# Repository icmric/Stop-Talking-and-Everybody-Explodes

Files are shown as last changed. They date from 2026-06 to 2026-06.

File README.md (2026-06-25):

# Stop Talking and Everybody Explodes
Stop talking and everybody explodes is an open-source take on the popular computer game [Keep Talking and Everybody Explodes](https://keeptalkinggame.com/), transforming it into a physical game to play with your friends!

You must work closley with the other player to solve a series of puzles and work around events all before the time runs out, resulting in a regrettable increase in room temperature!

This game is best enjoyed by using a physical copy of the manual (download and print manual.pdf), however an online mobile-friendly version is also avalible at [manual.ericmcc.com](https://manual.ericmcc.com/) (or the raw pdf at [staee.ericmcc.com](https://staee.ericmcc.com/))

This game was put together by a team of 6 of us for a university project, while there may be some future updates made we do not gaurantee any further maintinance

## Build Process
All components used are very generic and inexpencive. I have linked each item below to where i purchased it on aliexpress, however I recomend looking for potentially better prices as they change often! 

### Hardware
* [Arduino Mega 2560](https://www.aliexpress.com/item/32837393855.html)
* [LED Bar](https://www.aliexpress.com/item/1005007198230035.html) (Note: You must solder a 220Ω or 330Ω resistor on EVERY positive terminal for it to function. Pre wired ones basically dont exist, [there are some](https://www.aliexpress.com/item/1005007804923693.html) however they require seperate packages and work a bit differently)
* [TM1637 4 bit display](https://www.aliexpress.com/item/1005009269502486.html)
* 2x [Rotary Encoders](https://www.aliexpress.com/item/1005009578504178.html)
* [Microphone switch](https://www.aliexpress.com/item/1005009742731611.html)
* [Small buzzer](https://www.aliexpress.com/item/1005007287329656.html)
* [WS2182B-64 8x8 RGB LED Matrix](https://www.aliexpress.com/item/1005010747838637.html)
* [I<sup>2</sup>C LCD Display](https://www.aliexpress.com/item/1005011648206201.html)
* The + and - rail from a [400 pin bread board](https://www.aliexpress.com/item/1005006713173854.html)
* [12mm Key Switch](https://www.aliexpress.com/item/1005009886103118.html)
* 2x [12mm Momentary Push Switch](https://www.aliexpress.com/item/32814739163.html) (Note: A pre wired one may be wise as the raw connectors are very difficult to solder)
* A bunch of 10mm and 20mm [DuPont Cables](https://www.aliexpress.com/item/4000204858217.html)
* A small power bank, any should work but i use [this one](https://www.aliexpress.com/item/1005008094289372.html)

Not directly avalible for purchase is the enclosure which is custom made. All required files have been included so you can print your own!
  
  **Note:** For standard 3d prints use the .STL files, if you would like to print the text in a different colour use the .3mf file. There is also the .f3d if you would like to tweak the design!
  
  **Note:** Make sure you print **10** of the DuPont holders, my recomendation is to print using 5 colours (printing 2 in each colour) however you *could* get away without this

### Software
* Install the [Arduino IDE](https://docs.arduino.cc/software/ide/), download the code in the repository, unzip it and open it using the IDE
* There are a few external packages you must install in the IDE to get everything working, these are all listed at the top of the .ino file!
* After everything is installed connect up the arduino to your computer and upload the code

### Setup
Now that the ardino has the software uploaded to it, disconnect it from the computer before plugging in all the hardware

The .ino file contains a pin map at the top detailing which pin must be connceted to which component. Make sure you also connect up all the VCC and GND pins to the breadboard, connecting each rail to the arduino!

I would also sugest putting a bit of hot glue on the connectors as the DuPont cables can sometimes slide off the components, however you can probably get away without glue.

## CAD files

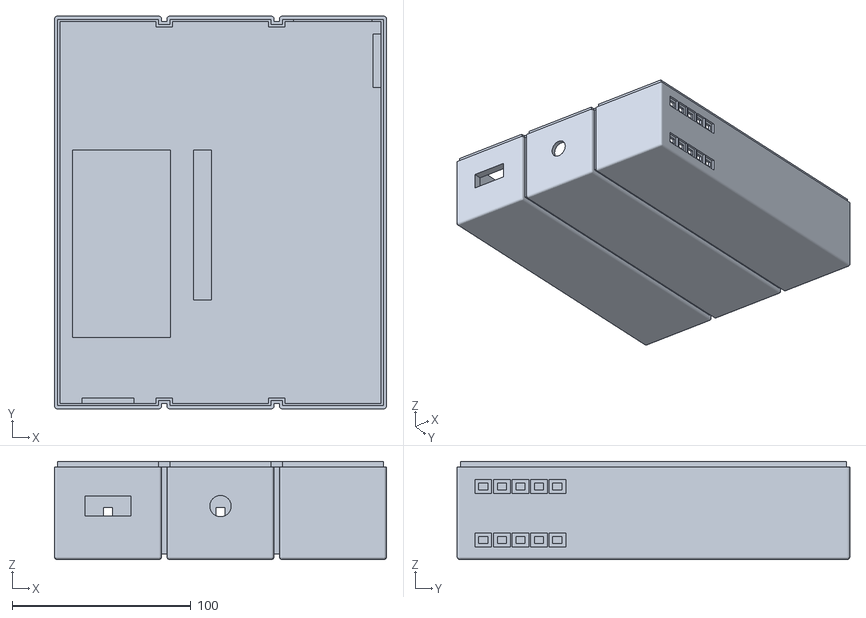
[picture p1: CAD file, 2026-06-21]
3D Models/Body.stl
186.0 x 220.0 x 55.0

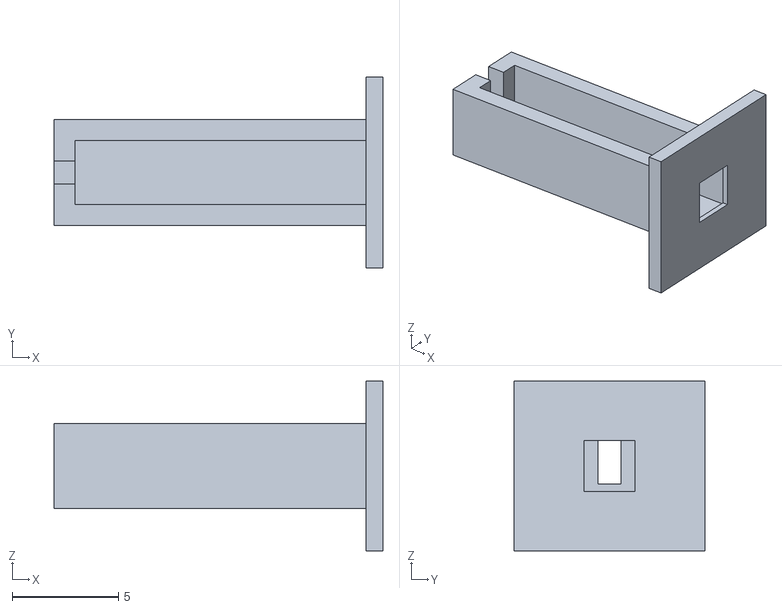
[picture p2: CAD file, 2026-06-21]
3D Models/DuPont Adaptor.stl
15.5 x 9.00 x 8.00

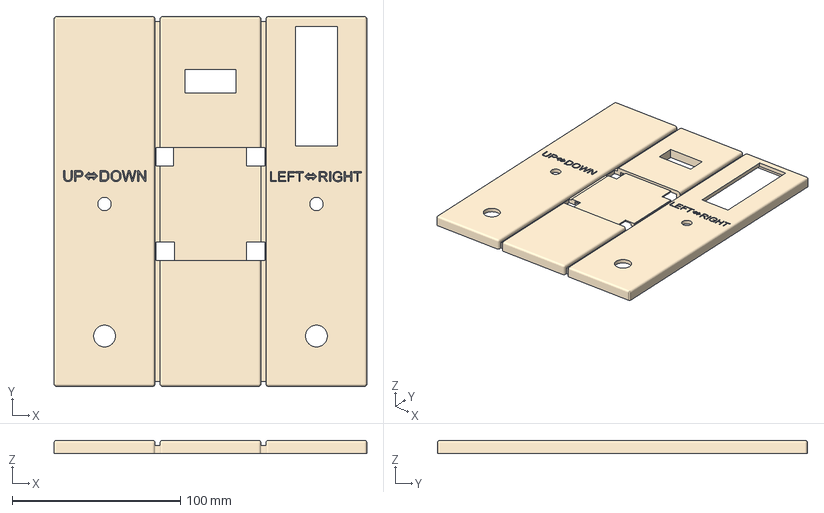
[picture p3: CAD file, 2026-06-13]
3D Models/Lid.3mf
186.0 x 220.0 x 8.00 mm
ARR
G
H
I
Lid
R
T
arr
d
e
f
l
n
o
p
t
u
w

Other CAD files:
3D Models/Lid.stl
3D Models/Stop talking and Everybody Explodes.f3d

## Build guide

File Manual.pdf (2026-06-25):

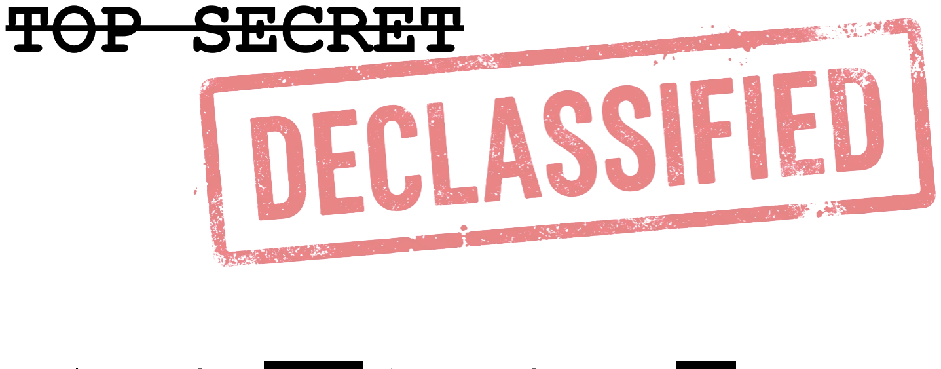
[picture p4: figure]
TOP SECRET

Authority: Executive Order | 13526 | | Record Group | 218

# OPERATIONAL FIELD MANUAL: EX-99

## EXPLOSIVE DEVICE NEUTRALISATION & DISPOSAL PROCEDURES

FILE NO: | 88-B-ALPHA-9
PREPARED BY: | DEFENSE SPECIAL WEAPONS AGENCY

DATE OF DECLASSIFICATION: MAY 13, 2026 Reason: Request under Freedom of Information Act 1982

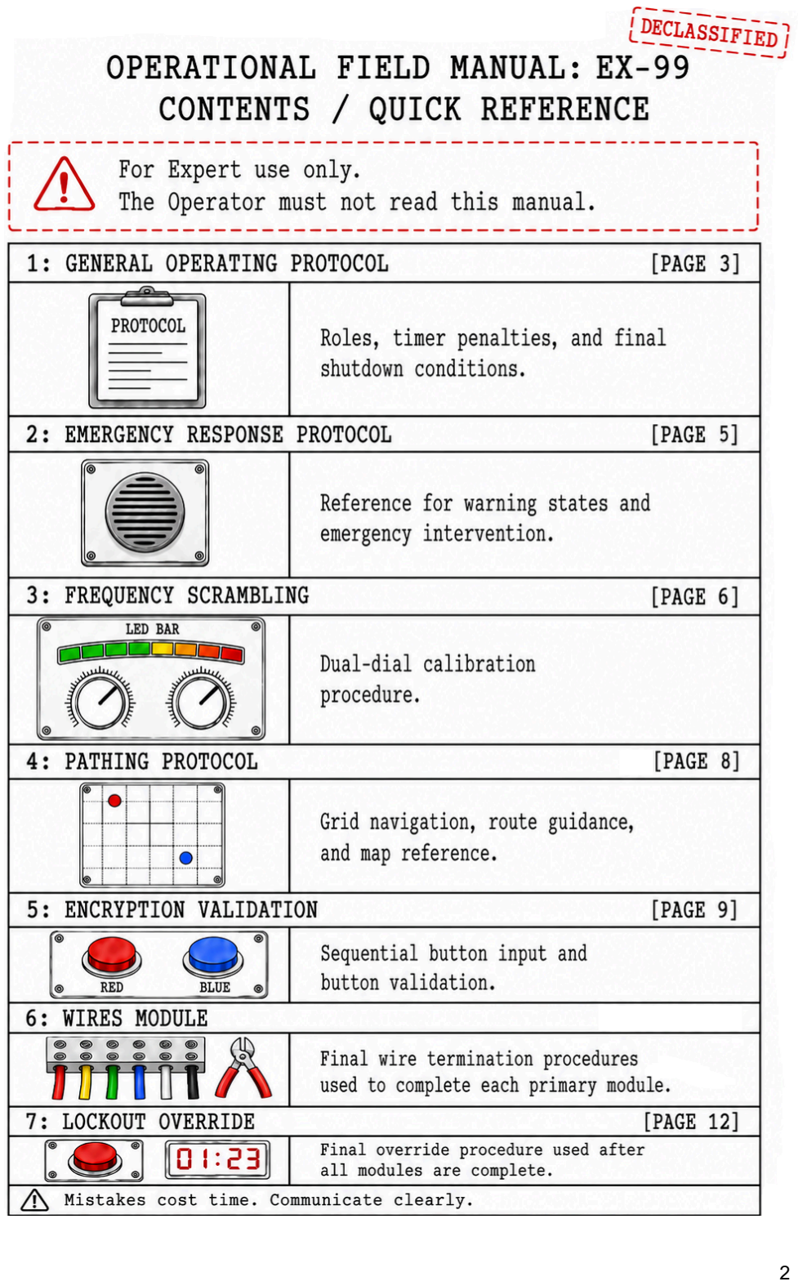
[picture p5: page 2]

## SECTION 0 一 GENERAL OPERATING PROTOCOL

DOCUMENT CLASSIFICATION: RESTRICTED ACCESS
SUBJECT: EXPLOSIVE DEVICE DEFUSAL PROCEDURE

MISSION OBJECTIVE: PROJECT FIRECRACKER (CONFIDENTIAL)
Your primary directive is to guide your field asset through the non-destructive neutralisation of an active, multi-module explosive device before the clock runs out. Failure to follow these exact procedures will result in a rapid increase in room temperature.

### 0.1 The Golden Rules

Corporate liability insurance strictly covers your designated role and your role only:
- The Expert (You): The brains, you must maintain zero physical and visual contact with the bomb. Far too risky up close anyway.
- The Operator: They are the hands, they are paid to turn dials and pull wires. Reading this manual is well above their pay grade.

### 0.2 Shift Schedule

To ensure compliance with labour laws, please closely follow this procedure:
- Managing Time: Keep watching the timer. This lets you know how long you have until you lose. It cannot be paused or reset, and will not wait for you to refill your coffee.
- Efficiency Tax: Being bad at your jobs is ill-advised. Any mistake made by the operator tends to cause instability in the device, resulting in the loss of at least 3 seconds.
- Clock in: When you’re ready to begin, get the operator to pick up the key, insert it and turn the device on. Congratulations, you are now in danger
- Clocking out: Once and only once every single section is fully neutralised, the operator must turn the key to the OFF position. Turning it off before properly neutralising the device is ill advised due to the sheer amount of paperwork and clean-up involved.

# Module Defusal Procedures

## EXPERT EYES ONLY

===================================

## ⚠ EMERGENCY RESPONSE PROTOCOL ⚠

===================================

### THERMAL INSTABILITY DETECTED

The amateur who wired up the device clearly didn't understand much about power regulation. Whenever a module is taken offline there is a sudden and violent voltage spike which has a chance to send the bomb into thermal runaway, which even for a bomb is pretty unsafe.

Luckily due to their poor design knowledge the workaround is incredibly simple, and from our understanding should hopefully also prevent it from overheating in the future. The only slight downside is that it requires the operator sticking their face within a few centimetres of the device while it's unstable!

Whenever a module is taken offline there is a chance to send the bomb into thermal runaway!

This will be made evident by the following indicators:
- Some displays beginning to flicker
- The screen displays “Core Overheating”
- A really annoying alarm sound

When the operator experiences any of these things, IMMEDIATELY return to this page. Tell the operator to stop what they are doing and perform the following steps:
- Look for a circular black vent on the back right of the device.
- Blow into the vent to cool it down.
- Maintain a constant stream of cool air until the beeping stops, this should only take about 5-10 seconds.

## SECTION 1 一 FREQUENCY SCRAMBLING MODULE

DOCUMENT CLASSIFICATION: RESTRICTED ACCESS
MODULE DESIGNATION: DUAL-DIAL CALIBRATION SYSTEM MODULE ID: 54F-3W1-R35

### 1.1 Dial Calibration Protocol

This module requires the Operator to turn the two dials in a specific sequence to scramble the communication systems within the bomb. Extensive research shows that there are 5 possible combinations the device could want, all helpfully tied to the serial number. Figuring out which combination to use takes only a little bit of primary school maths.

Incorrect inputs will incur a 3 second penalty.

- Sum the 4 digits of the serial number (ABCD-XXXX).
- Calculate the sum of these digits, modulo 5 (keep subtracting 5 until you can’t, it's the number left over).
- Look that number up in the table below and instruct the operator to turn the corresponding dials until they click the respective number of times.

They’ll know they’ve done this step correctly if the LED bar on the front of the device decreases after each set of dial turns.
0 | 1 | 2 | 3 | 4
3 DOWN | 2 RIGHT | 4 DOWN | 3 RIGHT | 1 UP
2 LEFT | 3 UP | 1 LEFT | 2 UP | 4 RIGHT
2 UP | 1 RIGHT | … | 1 LEFT | 1 DOWN
… | … | … | 2 DOWN | …

### 1.2 Terminal Node De-Energisation

After successfully scrambling the frequencies, you need to have the Operator permanently disable the communication module, by cutting or ripping out the wires on the side of the device.

The behaviour of the device if the Operator cuts the wrong wire is technically "unknown". Common speculation around the office is that it will trigger an immediate detonation, drastically shorten the countdown timer, or do absolutely nothing at all. Given the total lack of consensus, we strongly recommend you actually pay attention to the next step so the Operator doesn't fumble the only direct instruction you're about to give them.

Be Careful, if the Operator cuts the wrong wire it will trigger an immediate detonation!
- Ask the operator for the final digit in the serial number (ABCD-123X).
- Take this number to the handy table below and find the corresponding target wire.
- Tell the operator to terminate the wire. (Or just pull).
Serial Number Final Digit | Target Wire
0 or 5 | 🟥 RED (1) 🟥
1 or 6 | 🟦 BLUE (2) 🟦
2 or 7 | 🟨 YELLOW (3) 🟨
3 or 8 | 🟩 GREEN (4) 🟩
4 or 9 | ⬛ BLACK (5) ⬛
* The number denotes the wire when looking at the top row of plugs, count from left to right

## SECTION 2 一 PATHING PROTOCOL MODULE

DOCUMENT CLASSIFICATION: RESTRICTED ACCESS MODULE DESIGNATION: GRID-BASED PATHFINDING SYSTEM MODULE ID: M4Z-3W1-R35

### 2.1 Interface Asymmetry

The operator should now have a grid of dots light up on the front of the device. This is an invisible maze. The operator cannot see the walls, but luckily, you can.
Through a monumental waste of our department's afternoon we managed to reverse-engineer these layouts for this manual.

Do not allow them to turn dials randomly; we do not have the budget for another prolonged structural incident.

### 2.2 Map Identification

The hardware cycles through four separate layout configurations.
To identify which structural failure you are dealing with:
- Extract the second letter of the device serial number (AXCD-1234) from the Operator.
- Match that letter to the corresponding ranges to isolate the active map on the following page.

### 2.3 OPERATION PROTOCOL

Once the structural layout is identified, clear the active grid parameters by following the strict sequence:
- Instruct the Operator to relay the location of the two active glowing dots.
- The Red Dot represents the Operator’s current position.
- The Blue Dot identifies the intended target destination.
- Relay navigation instructions to the Operator one step at a time.

Any physical collision between the Operator and a grid wall will result in an immediate 3-second time penalty.

A - G

O - U

H - N

V - Z

### 2.4 Terminal Node De-Energisation

Bypassing the software layer merely advances your shift closer to standard clock-out parameters. To permanently drop the pathing algorithms offline, you must additionally command a physical hardware termination.

While the internal analytics department remains reasonably confident in this data matrix , any unexpected post-mortem detonation must be
manually documented and reported to Sgt. | redacted | for internal
investigation.

Be Careful, if the Operator cuts the wrong wire it will trigger an immediate detonation!

1. Request the first digit of the serial number (ABCD-X234) from the operator.
2. Match that digit to the matrix below to isolate the designated wire.
3. Tell the operator to terminate the wire. (Or just pull).
Serial Number First Digit | Target Wire
0 or 1 | 🟦 BLUE (2) 🟦
2 or 3 | 🟨 YELLOW (3) 🟨
4 or 5 | 🟩 GREEN (4) 🟩
6 or 7 | ⬛ BLACK (5) ⬛
8 or 9 | 🟥 RED (1) 🟥

## SECTION 3 一 ENCRYPTION VALIDATION MODULE

DOCUMENT CLASSIFICATION: RESTRICTED ACCESS
MODULE DESIGNATION: SEQUENTIAL INPUT VALIDATION SYSTEM MODULE ID: 3V3-N0D-DW1

### 3.1 Description

The architect of this device implemented a sequential validation system to weed out operators with sub-standard short-term memory. The module consists of a red and a blue button.

Instruct the Operator to, in quick succession, input the button sequence derived from the serial number digits read left to right:
- Even numbers: Direct operator to press the RED Button
- Odd numbers: Direct operator to press the BLUE Button

### 3.2 Terminal Node De-Energisation

Disconnecting this hardware layer is an administrative nightmare because our software division is entirely incompetent, leaving this routing matrix unnecessarily convoluted

- Request the last letter of the serial number (ABCX-1234) from the Operator.
- Isolate the designated wire via the chart below.
- Instruct the Operator to terminate the wire. If a sudden detonation occurs, file a formal grievance report regarding the intern's logic.
Serial Number Last Letter | Target Wire
A, F, K, P, U, OR Z | 🟨 YELLOW (3) 🟨
B, G, L, Q, V, OR W | 🟩 GREEN (4) 🟩
C, H, M, R, X, OR Y | ⬛ BLACK (5) ⬛
D, I, N, S, OR T | 🟥 RED (1) 🟥
E, J, OR O | 🟦 BLUE (2) 🟦

## SECTION 4 一 LOCKOUT OVERRIDE MODULE

DOCUMENT CLASSIFICATION: RESTRICTED ACCESS MODULE DESIGNATION: REACTION TRIGGER EMERGENCY MODULE ID: B16-R3D-BU7

### 4.1 OPERATION PROTOCOL

The amateur threat lazily mapped this final lockout override routine directly to the same red button utilised during your encryption sequence. Once all other threats are entirely offline, the Operator may resolve this final corporate hurdle by observing the following protocol:

- Instruct the Operator to closely watch the timer count down and preferably remain calm.
- Direct the Operator to press the red button when the number in the third digit of the serial number (ABCD-12X4), appears in any position on the timer.

Commanding this input incorrectly may result in the permanent, post-mortem conclusion of your corporate employment. Once this final validation layer is cleared, refer back to your initial Shift Schedule to determine the proper administrative procedure required to officially wrap up your shift.

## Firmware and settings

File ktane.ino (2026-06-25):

/*
  ktane.ino — KTANE Bomb Defusal Game
  Arduino Mega 2560

  Players solve multiple hardware puzzle modules under a countdown timer.
  A "Defuser" operates the hardware; a "Manual Operator" reads the solution
  guide derived from the randomly-generated serial number displayed on the LCD.

  MODULES:
    Frequency Scrambler  — rotary encoder sequence
    Maze Navigator       — LED matrix pathfinding (shares encoders with Frequency)
    Core Overheating     — blow-to-cool microphone event (random trigger)
    Button Combo         — timed button sequence

  PIN MAP:
    D2, D3   Left encoder  (CLK / DT)
    D4, D5   Right encoder (CLK / DT)
    D6       Buzzer
    D7       Microphone sensor (Core module)
    D8, D9   4-digit TM1637 display (DIO / CLK)
    D10      Red button   (INPUT_PULLUP)
    D11      Blue button (INPUT_PULLUP)
    D12      Vibration motor (via transistor; active HIGH)
    D20, D21 I2C bus — LCD 16×2 (0x27)
    D22      8×8 WS2812B matrix (NeoPixel data)
    D31      Key switch
    D35,37,39,41,43,45,47,49,51,53  LED bar (10 LEDs)
    
    HARDWARE WIRE CUTTING INTERFACE (Ground-to-Pin Arrays):
    A7       Color 0: RED
    A6       Color 1: BLUE
    A5       Color 2: YELLOW
    A4       Color 3: GREEN
    A3       Color 4: BLACK
*/

#include <Wire.h>
#include <Encoder.h>
#include <LiquidCrystal_I2C.h>
#include <Adafruit_NeoPixel.h>
#include <DIYables_4Digit7Segment_TM1637.h>

#include "SerialNumber.h"

// ── Module enable enum — defined before module headers ─────────────────────

enum ActiveEncoderModule { FREQUENCY_MODULE, MAZE_MODULE };

enum GameState {
  STATE_IDLE,      // Waiting for key turn
  STATE_RUNNING,   // Game in progress
  STATE_WON,       // All modules solved; waiting for key-off to confirm disarm
  STATE_FAILED,    // Timer expired or key turned off early
  STATE_DISARMED   // Successfully disarmed
};

// ── Module headers (after enum definitions) ────────────────────────────────

#include "FrequencyModule.h"
#include "CoreModule.h"
#include "MazeModule.h"
#include "ButtonComboModule.h"
#include "LockoutModule.h"

// ── Debug / bypass flags ───────────────────────────────────────────────────
// Set to true to skip a module during development/testing.

const bool BYPASS_FREQUENCY_MODULE = false;
const bool BYPASS_MAZE_MODULE = false;
const bool BYPASS_CORE_MODULE = false;
const bool BYPASS_BUTTON_COMBO = false;
const bool BYPASS_LOCKOUT_MODULE = false;

// When true, skips the key-switch requirement and starts immediately on boot.
const bool AUTO_START_GAME = false;

// ── Pin definitions ────────────────────────────────────────────────────────

const int BUZZER_PIN = 6;
const int VIBRATION_PIN = 12;
const int KEY_SWITCH_PIN = 31;

const int ENC_LEFT_A = 2, ENC_LEFT_B = 3;
const int ENC_RIGHT_A = 4, ENC_RIGHT_B = 5;

const int DISP_DIO = 8, DISP_CLK = 9;
const int NEOPIXEL_PIN = 22;
const int NUM_PIXELS = 64;

const int LED_BAR_PINS[10] = {53, 51, 49, 47, 45, 43, 41, 39, 37, 35};

// ── Hardware objects ───────────────────────────────────────────────────────

Encoder encLeft (ENC_LEFT_A,  ENC_LEFT_B);
Encoder encRight(ENC_RIGHT_A, ENC_RIGHT_B);
LiquidCrystal_I2C lcd(0x27, 16, 2);
DIYables_4Digit7Segment_TM1637 tm1637(DISP_CLK, DISP_DIO);
Adafruit_NeoPixel matrix(NUM_PIXELS, NEOPIXEL_PIN, NEO_GRB + NEO_KHZ800);

// ── Game state ─────────────────────────────────────────────────────────────

ActiveEncoderModule activeEncoderModule = FREQUENCY_MODULE;
GameState currentGameState = STATE_IDLE;
String bombSerialNumber = "";

// ── Timer ──────────────────────────────────────────────────────────────────

const int TIMER_START_MINUTES  = 6;
const unsigned long TIMER_TOTAL_DURATION = (unsigned long)TIMER_START_MINUTES * 60UL * 1000UL;

int remainingSeconds = TIMER_START_MINUTES * 60;
bool timerRunning = false;
bool timerFinished = false;
unsigned long timerLastTick = 0;

// currentDigits mirrors the live display (MM:SS as four single digits)
int currentDigits[4] = {0, 5, 0, 0};

// ── Display state ──────────────────────────────────────────────────────────

bool serialNumberDisplayed = false;
int  lastDisplayedGameState = -1;

// ── Buzzer / vibration ─────────────────────────────────────────────────────

unsigned long buzzerLastBeepTime = 0;
unsigned long vibrationEndTime = 0;
bool vibrationContinuous = false;

const unsigned long BUZZER_INTERVAL_START = 5000;
const unsigned long BUZZER_INTERVAL_END = 90;
const unsigned long BUZZER_BEEP_DURATION = 80;
const int BUZZER_FREQ_START = 800;
const int BUZZER_FREQ_END = 2000;
const float BUZZER_INTERVAL_CURVE = 3.5f;
const float BUZZER_PITCH_CURVE = 2.8f;

void startVibration(unsigned long durationMs = 0);
void stopVibration();
void updateVibration();
void buzzerTone(int frequency, unsigned long duration);
void buzzerToneWait(int frequency, unsigned long duration, unsigned long waitMs);
void stopBuzzer();

// ── Key switch debounce ────────────────────────────────────────────────────

bool keyCurrentState = false;
bool keyLastState = false;
unsigned long keyLastChangeTime = 0;
const unsigned long KEY_DEBOUNCE_DELAY = 50;

// ── Wire-Cutting Tracking Hardware Variables ───────────────────────────────

bool frequencyWirePulled = false;
bool mazeWirePulled = false;
bool buttonComboWirePulled = false;

bool lastFrequencyWirePulled = false;
bool lastMazeWirePulled = false;
bool lastButtonComboWirePulled = false;

// ── End-sequence guard ─────────────────────────────────────────────────────

bool endSequencePlayed = false;

// =============================================================================
// LED BAR
// =============================================================================

void initializeLedBar() {
  for (int i = 0; i < 10; i++) {
    pinMode(LED_BAR_PINS[i], OUTPUT);
    digitalWrite(LED_BAR_PINS[i], LOW);

  }
}

void setLedLevel(int level) {
  level = constrain(level, 0, 10);
  for (int i = 0; i < 10; i++)
    digitalWrite(LED_BAR_PINS[i], i < level ? HIGH : LOW);
}

// =============================================================================
// MODULE QUERIES
// =============================================================================

bool allModulesSolved() {
  if (!BYPASS_FREQUENCY_MODULE && !(frequencyModuleSolved && frequencyWirePulled)) return false;
  if (!BYPASS_MAZE_MODULE && !(mazeSolved && mazeWirePulled)) return false;
  if (!BYPASS_CORE_MODULE && !coreSolved) return false;
  if (!BYPASS_BUTTON_COMBO && !(buttonComboSolved && buttonComboWirePulled)) return false;
  if (!BYPASS_LOCKOUT_MODULE && !lockoutOverrideSolved) return false;
  return true;
}

int getTotalModuleCount() {
  int n = 0;
  if (!BYPASS_FREQUENCY_MODULE) n++;
  if (!BYPASS_MAZE_MODULE) n++;
  if (!BYPASS_CORE_MODULE) n++;
  if (!BYPASS_BUTTON_COMBO) n++;
  if (!BYPASS_LOCKOUT_MODULE) n++;
  return n;
}

int getSolvedModuleCount() {
  int n = 0;
  if (!BYPASS_FREQUENCY_MODULE && frequencyModuleSolved && frequencyWirePulled) n++;
  if (!BYPASS_MAZE_MODULE && mazeSolved && mazeWirePulled) n++;
  if (!BYPASS_CORE_MODULE && coreSolved) n++;
  if (!BYPASS_BUTTON_COMBO && buttonComboSolved && buttonComboWirePulled) n++;
  if (!BYPASS_LOCKOUT_MODULE && lockoutOverrideSolved) n++;
  return n;
}

// =============================================================================
// PENALTY
// =============================================================================

void applyPenalty(const char* /*reason*/) {
  buzzerTone(1000, 200);
  if (remainingSeconds > 3) {
    remainingSeconds -= 3;
  } else {
    remainingSeconds = 0;
    timerRunning = false;
    timerFinished = true;
    noTone(BUZZER_PIN);
  }
}

// =============================================================================
// AUDIO
// =============================================================================

void startVibration(unsigned long durationMs) {
  digitalWrite(VIBRATION_PIN, HIGH);
  if (durationMs == 0) {
    vibrationContinuous = true;
    vibrationEndTime = 0;
  } else {
    vibrationContinuous = false;
    vibrationEndTime = millis() + durationMs;
  }
}

void stopVibration() {
  digitalWrite(VIBRATION_PIN, LOW);
  vibrationContinuous = false;
  vibrationEndTime = 0;
}

void updateVibration() {
  if (vibrationContinuous || vibrationEndTime == 0) return;
  if (millis() >= vibrationEndTime) {
    digitalWrite(VIBRATION_PIN, LOW);
    vibrationEndTime = 0;
  }
}

void buzzerTone(int frequency, unsigned long duration) {
  tone(BUZZER_PIN, frequency, duration);
  
  if (!vibrationContinuous) startVibration(duration);
}

void buzzerToneWait(int frequency, unsigned long duration, unsigned long waitMs) {
  buzzerTone(frequency, duration);
  unsigned long end = millis() + waitMs;
  while (millis() < end) updateVibration();
  if (!vibrationContinuous) stopVibration();
}

void stopBuzzer() {
  noTone(BUZZER_PIN);
  digitalWrite(BUZZER_PIN, LOW);
  if (!vibrationContinuous) stopVibration();
}

void playSuccessTone() {
  const int notes[] = {523, 659, 784, 1047, 784, 659, 523};
  for (int i = 0; i < 7; i++) {
    buzzerToneWait(notes[i], 150, 200);
  }
  stopBuzzer();
}

// Short single confirm
void playStepConfirmTone() {
  buzzerToneWait(1400, 90, 110);
}

// Three-tone ascending confirm
void playModuleCompleteTone() {
  buzzerToneWait(900, 80, 90);
  buzzerToneWait(1200, 80, 90);
  buzzerToneWait(1600, 120, 140);
}

float getTimerProgress() {
  long msLeft = (long)remainingSeconds * 1000L - (long)(millis() - timerLastTick);
  msLeft = constrain(msLeft, 0L, (long)TIMER_TOTAL_DURATION);
  return 1.0f - ((float)msLeft / (float)TIMER_TOTAL_DURATION);
}

void updateBuzzer() {
  // Core alert overrides normal beeping
  if (coreMessageShown && !coreSolved) {
    unsigned long cycleTime = millis() % 1000;
    
    // Determine if the buzzer should be actively making sound right now
    bool shouldBeOn = (cycleTime < 200 || (cycleTime >= 250 && cycleTime < 450) || (cycleTime >= 500 && cycleTime < 700));
    
    static bool lastCoreSoundActive = false;
    
    if (shouldBeOn) {
      if (!lastCoreSoundActive) {
        buzzerTone(1500, 200); // Fires ONCE at the exact start of a beep window
        lastCoreSoundActive = true;
      }
    } else {
      if (lastCoreSoundActive) {
        stopBuzzer(); // Fires ONCE at the exact start of a silent window
        lastCoreSoundActive = false;
      }
    }
    return;
  }

  if (!timerRunning || timerFinished || remainingSeconds <= 0) {
    stopBuzzer();
    return;
  }

  unsigned long now = millis();

  if (remainingSeconds <= 15) {
    unsigned long interval  = 100;
    int panicFreq = 1000 + (15 - remainingSeconds) * 50;
    if (now - buzzerLastBeepTime >= interval) {
      buzzerTone(panicFreq, 50);
      buzzerLastBeepTime = now;
    }
  } else {
    float t = getTimerProgress();
    unsigned long interval = BUZZER_INTERVAL_START -
      (unsigned long)((BUZZER_INTERVAL_START - BUZZER_INTERVAL_END) * pow(t, BUZZER_INTERVAL_CURVE));
    int freq = BUZZER_FREQ_START +
      (int)((BUZZER_FREQ_END - BUZZER_FREQ_START) * pow(t, BUZZER_PITCH_CURVE));
    if (now - buzzerLastBeepTime >= interval) {
      buzzerTone(freq, BUZZER_BEEP_DURATION);
      buzzerLastBeepTime = now;
    }
  }
}

// =============================================================================
// TIMER DISPLAY
// =============================================================================

void updateTimerDisplay() {
  int mins = remainingSeconds / 60;
  int secs = remainingSeconds % 60;
  currentDigits[0] = mins / 10;
  currentDigits[1] = mins % 10;
  currentDigits[2] = secs / 10;
  currentDigits[3] = secs % 10;
  tm1637.printTime(mins, secs, true);
}

void updateCountdown() {
  // Keep display current regardless of state
  if (currentGameState == STATE_RUNNING ||
      currentGameState == STATE_WON     ||
      currentGameState == STATE_FAILED) {
    updateTimerDisplay();
  }

  if (!timerRunning || timerFinished) return;

  if (millis() - timerLastTick >= 1000) {
    timerLastTick += 1000;
    if (remainingSeconds > 0) remainingSeconds--;

    if (remainingSeconds <= 0) {
      remainingSeconds = 0;
      timerRunning = false;
      timerFinished = true;
      stopBuzzer();
      
      if (currentGameState == STATE_RUNNING || currentGameState == STATE_WON) {
        currentGameState = STATE_FAILED;
        
        // FIX: Trigger the custom expanding explosion sequence upon running out of time
        if (!endSequencePlayed) {
          tm1637.printTime(00, 00, true);
          playDetonatedSequence(true); // Passes timedOut = true for the correct ending text
          endSequencePlayed = true;
        }
      }
    }
  }
}

// =============================================================================
// LCD DISPLAY MANAGEMENT
// =============================================================================

void updateModuleCountDisplay() {
  String s = String(getSolvedModuleCount()) + "/" + String(getTotalModuleCount());
  lcd.setCursor(16 - s.length(), 1);
  lcd.print(s);
}

void displaySerialNumber() {
  lcd.clear();
  lcd.setCursor(0, 0);
  lcd.print("SN:"); lcd.print(bombSerialNumber);
  updateModuleCountDisplay();
}

void updateDisplayState() {
  if (currentGameState != lastDisplayedGameState) {
    if (currentGameState == STATE_IDLE) {
      lcd.clear();
      lcd.setCursor(0, 0); lcd.print("BOMB ARMED");
      lcd.setCursor(0, 1); lcd.print("TURN KEY");
    }
    lastDisplayedGameState = currentGameState;
    serialNumberDisplayed  = false;
  }

  if (!serialNumberDisplayed &&
      (currentGameState == STATE_RUNNING || currentGameState == STATE_WON)) {
    if (!coreTriggered || coreSolved) {
      displaySerialNumber();
      serialNumberDisplayed = true;
    }
  }

  if (serialNumberDisplayed && (!coreTriggered || coreSolved))
    updateModuleCountDisplay();
}

// =============================================================================
// WIN / LOSE SEQUENCES
// =============================================================================

void playDisarmedSequence() {
  lcd.clear();
  lcd.setCursor(0, 0); lcd.print("** DISARMED **");
  lcd.setCursor(0, 1);
  int m = remainingSeconds / 60, s = remainingSeconds % 60;
  lcd.print(m); lcd.print(":");
  if (s < 10) lcd.print("0");
  lcd.print(s); lcd.print(" remaining");

  // Smoothly charge up the LED bar level
  for (int i = 1; i <= 10; i++) { 
    setLedLevel(i); 
    delay(60); 
  }

  // Cinematic Green Ripple Wave expanding outward from the center
  // dx and dy calculate the distance squared from the center 4 pixels using integer math
  for (int wave = 0; wave < 5; wave++) {
    // Satisfying ascending laser arpeggio paired with each wave step
    tone(BUZZER_PIN, 400 + (wave * 250), 60);
    
    for (int y = 0; y < 8; y++) {
      for (int x = 0; x < 8; x++) {
        int dx = 2 * x - 7;
        int dy = 2 * y - 7;
        int distSq = dx * dx + dy * dy;
        int pixelIdx = y * 8 + x;

        if (wave == 0 && distSq <= 2)   matrix.setPixelColor(pixelIdx, 0x00FF00); // Ring 0 (Center)
        if (wave == 1 && distSq == 18)  matrix.setPixelColor(pixelIdx, 0x00FF00); // Ring 1
        if (wave == 2 && distSq == 50)  matrix.setPixelColor(pixelIdx, 0x00FF00); // Ring 2
        if (wave == 3 && distSq >= 98)  matrix.setPixelColor(pixelIdx, 0x00FF00); // Ring 3 (Corners)
      }
    }
    matrix.show();
    delay(100);
    
    // Dim the trailing edge of the wave for a smooth ripple effect
    for(int i = 0; i < 64; i++) {
      uint32_t c = matrix.getPixelColor(i);
      if (c == 0x00FF00) matrix.setPixelColor(i, 0x003300); 
    }
  }
  noTone(BUZZER_PIN);

  // Bring the whole matrix up to a warm, triumphant solid green pulse
  for (int pulse = 0; pulse < 3; pulse++) {
    for (int i = 0; i < 64; i++) matrix.setPixelColor(i, 0x00FF00);
    matrix.show();
    delay(250);
    for (int i = 0; i < 64; i++) matrix.setPixelColor(i, 0x003300);
    matrix.show();
    delay(200);
  }

  // Clear display down to a pristine off state
  for (int i = 0; i < 64; i++) matrix.setPixelColor(i, 0x000000);
  matrix.show();

  lcd.clear();
  lcd.setCursor(0, 0); lcd.print("BOMB DISARMED");
  updateModuleCountDisplay();
}

void playDetonatedSequence(bool timedOut) {

  startVibration(); // Initiate continuous haptic rumble framework

  // Multi-Stage Expanding Plasma Fireball Animation
  // Steps iterate outward through concentric distance thresholds
  for (int step = 0; step < 8; step++) {
    // Generate a violent, chaotic explosion crackle sound pitch down
    tone(BUZZER_PIN, random(1800 - (step * 200), 2400 - (step * 200)), 40);

    for (int y = 0; y < 8; y++) {
      for (int x = 0; x < 8; x++) {
        int dx = 2 * x - 7;
        int dy = 2 * y - 7;
        int distSq = dx * dx + dy * dy;
        int pixelIdx = y * 8 + x;

        // Map colors dynamically relative to the expanding shockwave front
        if (distSq <= 2) { // Ring 0 (Center core)
          if (step < 2) matrix.setPixelColor(pixelIdx, 0xFFFFFF);      // Blinding white flash
          else if (step < 4) matrix.setPixelColor(pixelIdx, 0xFFCC00); // Hot yellow
          else if (step < 6) matrix.setPixelColor(pixelIdx, 0xFF4500); // Fire orange
          else matrix.setPixelColor(pixelIdx, 0x440000);               // Cooling ash
        } 
        else if (distSq > 2 && distSq <= 18) { // Ring 1
          if (step == 1) matrix.setPixelColor(pixelIdx, 0xFFFFFF);
          else if (step < 4) matrix.setPixelColor(pixelIdx, 0xFFCC00);
          else if (step < 6) matrix.setPixelColor(pixelIdx, 0xFF4500);
          else matrix.setPixelColor(pixelIdx, 0x330000);
        } 
        else if (distSq > 18 && distSq <= 50) { // Ring 2
          if (step == 2) matrix.setPixelColor(pixelIdx, 0xFFFFFF);
          else if (step == 3) matrix.setPixelColor(pixelIdx, 0xFFCC00);
          else if (step < 6) matrix.setPixelColor(pixelIdx, 0xFF4500);
          else matrix.setPixelColor(pixelIdx, 0x110000);
        } 
        else { // Ring 3 (Outer edge bounds)
          if (step == 3) matrix.setPixelColor(pixelIdx, 0xFFFFFF);
          else if (step == 4) matrix.setPixelColor(pixelIdx, 0xFFCC00);
          else if (step == 5) matrix.setPixelColor(pixelIdx, 0xFF4500);
          else if (step == 6) matrix.setPixelColor(pixelIdx, 0xFF0000);
          else matrix.setPixelColor(pixelIdx, 0x000000);
        }
      }
    }
    matrix.show();
    delay(60);
  }
  noTone(BUZZER_PIN);

  // Dissipation phase: Fiery residual sparks twinkling and cooling down to empty
  for (int fade = 0; fade < 12; fade++) {
    for (int i = 0; i < 64; i++) {
      uint32_t c = matrix.getPixelColor(i);
      if (c > 0 && random(100) < 35) {
        matrix.setPixelColor(i, 0x000000); // Pixel burns completely out
      } else if (c == 0xFF4500 || c == 0xFFCC00) {
        matrix.setPixelColor(i, 0x330000); // Cool down to dim deep red
      }
    }
    matrix.show();
    delay(70);
  }

  // Clear total matrix array layout completely before warning strobes
  for (int i = 0; i < 64; i++) matrix.setPixelColor(i, 0x000000);
  matrix.show();

  // Violent Post-Explosion Emergency Status Strobes
  for (int i = 0; i < 6; i++) {
    setLedLevel(10);
    for (int j = 0; j < 64; j++) matrix.setPixelColor(j, 0xFF0000); // Pure emergency red warning
    matrix.show();
    
    // Screaming low-frequency building layout alert tone
    buzzerTone(i % 2 == 0 ? 120 : 90, 50);
    
    unsigned long flashOn = millis() + 60;
    while (millis() < flashOn) updateVibration();
    
    setLedLevel(0);
    for (int j = 0; j < 64; j++) matrix.setPixelColor(j, 0x000000);
    matrix.show();
    noTone(BUZZER_PIN);
    
    unsigned long flashOff = millis() + 60;
    while (millis() < flashOff) updateVibration();
  }

  stopBuzzer();
  stopVibration();

  lcd.clear();
  lcd.setCursor(0, 0); lcd.print(timedOut ? "DETONATED"     : "GAME FAILED");
  lcd.setCursor(0, 1); lcd.print(timedOut ? "TIMER EXPIRED": "WIRE FAULT / KEY OFF");
}

// =============================================================================
// KEY SWITCH
// =============================================================================

bool readKeySwitchDebounced() {
  bool reading = digitalRead(KEY_SWITCH_PIN);
  unsigned long now = millis();
  if (reading != keyLastState) keyLastChangeTime = now;
  if ((now - keyLastChangeTime) >= KEY_DEBOUNCE_DELAY && reading != keyCurrentState) {
    keyCurrentState = reading;
    keyLastState    = reading;
    return true;
  }
  keyLastState = reading;
  return false;
}
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
void loop() {
  updateVibration();
  handleKeySwitch();
  updateGameState();
  updateDisplayState();
  updateCountdown();
  updateBuzzer();

  if (currentGameState != STATE_RUNNING && currentGameState != STATE_WON) return;

  // Process live hardware link infrastructure checks
  updateWireCutting();

  checkModuleTransitionsAndTriggerCore();
  updateCoreModule();

  // Button combo is always interactable, even during Core event
  updateButtonComboModule();
  updateLockoutModule();

  // All other modules pause while Core is active
  if (!coreTriggered || coreSolved) {
    
    // Explicit lockout override protection to prevent encoder bleed through
    if (frequencyModuleSolved && !frequencyWirePulled) {
      activeEncoderModule = FREQUENCY_MODULE;
    } else if (frequencyModuleSolved && frequencyWirePulled && activeEncoderModule == FREQUENCY_MODULE) {
      activeEncoderModule = MAZE_MODULE;
    }

    if (activeEncoderModule == FREQUENCY_MODULE) {
      updateFrequencyModule();
    } else {
      updateMazeModule();
    }
  }
}

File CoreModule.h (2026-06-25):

#ifndef CORE_MODULE_H
#define CORE_MODULE_H

/*
  CoreModule.h
  Core Overheating event — triggered randomly after another module completes.

  The player must blow continuously into the microphone for a total of
  5 seconds (accumulated) to cool the core. Detection uses a rolling
  window majority-vote to reject brief/stray signals while still
  tolerating natural breath pauses.

  Hardware:
    - Sound sensor: digital pin (active-LOW — LOW = sound detected, HIGH = quiet)
    - 16×2 I2C LCD: address 0x27 (SDA/SCL)
*/

#include <LiquidCrystal_I2C.h>

extern DIYables_4Digit7Segment_TM1637 tm1637;
extern void setLedLevel(int level);

// ── Timing constants ──────────────────────────────────────────────────────

const int           MIC_SENSOR_PIN      = 7;
const unsigned long MIC_SAMPLE_INTERVAL = 40;   // ms between raw samples
const int           MIC_WINDOW_SIZE     = 30;   // samples in rolling window (30 * 10ms = 300ms window)
const int           MIC_HIGH_THRESHOLD  = 10;   // need at least this many "detected" samples in the window to count as blowing (tune this)

const unsigned long MIC_BREATH_TIMEOUT  = 700;   // Allow up to 600ms silence between breaths
const unsigned long BLOW_DURATION       = 5000;  // Total accumulation needed to solve
const unsigned long FLASH_DURATION      = 3000;  // Alert flash phase length
const unsigned long FLASH_CYCLE         = 500;   // Half-period (2Hz = 500ms on/off)

// ── State ───────────────────────────────────────────────────────────────────

bool coreSolved        = false;
bool coreTriggered     = false;
bool coreFlashing      = false;
bool coreBlowing       = false;
bool coreMessageShown  = false;
bool coreDisplayCleared = false;

unsigned long coreLastMicRead        = 0;
unsigned long micLastDetectionTime   = 0;
unsigned long coreFlashStart         = 0;
unsigned long coreSolvedTime         = 0;
unsigned long coreAccumulatedBlowTime = 0;

// ── Rolling window state ─────────────────────────────────────────────────────

bool micWindow[MIC_WINDOW_SIZE] = {false};
int  micWindowIndex      = 0;
int  micWindowHighCount  = 0;
bool micWindowFilled     = false;

extern LiquidCrystal_I2C lcd;
extern String bombSerialNumber;
extern int currentDigits[4];
extern bool serialNumberDisplayed;

// ── Helpers ───────────────────────────────────────────────────────────────────

bool isCoreFlashing() {
  if (!coreFlashing) return false;
  if (millis() - coreFlashStart >= FLASH_DURATION) {
    coreFlashing = false;
    return false;
  }
  return true;
}

bool getCoreFlashState() {
  return (((millis() - coreFlashStart) / FLASH_CYCLE) % 2) == 0;
}

// Resets the rolling window to all-empty. Call whenever a fresh Core
// event starts, so leftover samples from a previous round can't bleed in.
void resetMicWindow() {
  for (int i = 0; i < MIC_WINDOW_SIZE; i++) micWindow[i] = false;
  micWindowIndex     = 0;
  micWindowHighCount = 0;
  micWindowFilled    = false;
}

// Takes one raw sample, updates the rolling window, and returns whether
// the window currently has enough "detected" samples to count as blowing.
// rawDetected should already be polarity-corrected (true = sound detected).
bool updateMicWindow(bool rawDetected) {
  if (micWindow[micWindowIndex]) micWindowHighCount--;  // remove outgoing sample
  micWindow[micWindowIndex] = !rawDetected;
  if (!rawDetected) micWindowHighCount++;                // add incoming sample

  micWindowIndex++;
  if (micWindowIndex >= MIC_WINDOW_SIZE) {
    micWindowIndex  = 0;
    micWindowFilled = true;
  }

  // Until the window has filled once, judge against samples taken so far
  // rather than waiting the full window duration before responding at all.
  return micWindowHighCount >= MIC_HIGH_THRESHOLD;
}

// ── Public API ────────────────────────────────────────────────────────────────

void setupCoreModule() {
  pinMode(MIC_SENSOR_PIN, INPUT);
  lcd.init();
  lcd.backlight();
  lcd.clear();
}

void triggerCoreEvent() {
  if (coreTriggered || coreSolved) return;

  coreTriggered           = true;
  coreFlashing            = true;
  coreFlashStart          = millis();
  coreMessageShown        = false;
  coreAccumulatedBlowTime = 0;
  coreBlowing             = false;
  coreLastMicRead         = millis();
  micLastDetectionTime    = millis();

  resetMicWindow();

  extern bool mazeSetupDone;
  extern void clearMazeDisplay();
  if (mazeSetupDone) clearMazeDisplay();
}

void updateCoreModule() {
  if (!coreTriggered) return;

  unsigned long now = millis();

  // ── Alert flash phase ──────────────────────────────────────────────────────
  if (coreFlashing) {
    if (now - coreFlashStart < FLASH_DURATION) {
      bool on = getCoreFlashState();
      if (on) {
        lcd.backlight();
        setLedLevel(10);
        int v = currentDigits[0]*1000 + currentDigits[1]*100 + currentDigits[2]*10 + currentDigits[3];
        tm1637.print(v);
      } else {
        lcd.noBacklight();
        setLedLevel(0);
        tm1637.print(0);
      }

      if (!coreMessageShown) {
        lcd.clear();
        lcd.setCursor(0, 0); lcd.print("CORE OVERHEAT!");
        lcd.setCursor(0, 1); lcd.print("BLOW TO COOL");
        coreMessageShown = true;
      }
    } else {
      coreFlashing = false;
      lcd.backlight();
      setLedLevel(0);
    }
  }

  // ── Post-solve display clear ───────────────────────────────────────────────
  if (coreSolved) {
    if (!coreDisplayCleared && now - coreSolvedTime >= 2000) {
      lcd.clear();
      coreDisplayCleared    = true;
      serialNumberDisplayed = false;
    }
    return;
  }

  // ── Microphone sampling (fast raw sample, fed into rolling window) ─────────
  if (now - coreLastMicRead < MIC_SAMPLE_INTERVAL) return;
  unsigned long deltaTime = now - coreLastMicRead;
  coreLastMicRead = now;

  // Sensor is active-LOW: LOW = sound detected, HIGH = quiet.
  bool rawDetected = (digitalRead(MIC_SENSOR_PIN) == LOW);
  bool windowDetected = updateMicWindow(rawDetected);

  Serial.println(micWindowHighCount);

  if (windowDetected) {
    micLastDetectionTime = now;
    coreBlowing = true;
    coreAccumulatedBlowTime += deltaTime;  // only grows while the window says "blowing"
  } else if (coreBlowing) {
    if (now - micLastDetectionTime >= MIC_BREATH_TIMEOUT) {
      // Silence too long — give up progress
      coreBlowing             = false;
      coreAccumulatedBlowTime = 0;
      if (coreMessageShown && !coreFlashing) {
        lcd.setCursor(0, 1);
        lcd.print("BLOW TO COOL    ");
      }
    }
    // else: just a short breathing gap — accumulated time stays frozen, not reset
  }

  // ── Progress display & solve check ───────────────────────────────────────
  if (coreBlowing) {
    int secLeft = (BLOW_DURATION - coreAccumulatedBlowTime) / 1000 + 1;

    lcd.setCursor(0, 1);
    lcd.print("KEEP BLOWING: ");
    lcd.print(secLeft);
    lcd.print("s ");
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

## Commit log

2026-03-25 added encoder tuning game
2026-03-25 Implemented core overheating 'event'
    Added core overheating module with DHT11 sensor and LCD (I2C) display.
    May need to be tweaked once I get a reply on what exact sensor we have
    [ktane.ino]
2026-03-26 Initialise encoder positions and increased DHT delay for overheating module
    Added initialisation for lastLeftPos and lastRightPos to prevent incorrect encoder readings at startup. Adjusted temperature sensor failure handling with a delay for better reliability.
    [ktane.ino]
2026-03-26 Changed core overheating from using temp to humidity
    Changed core overheating to req 90%+ humidity for 10 secs. Can easily tweak constants HUMIDITY_THRESHOLD and BLOW_DURATION
    [ktane.ino]
2026-04-29 combined modules
    Timer,
    Big Red Button,
    Maze,
    Buzzer,
    Encoder Tuning,
    [ktane.ino]
2026-04-29 Added Distance Control and Button Combo modules, removed old ktane file
2026-05-01 Key working. Added button combo and distance module (UNTESTED)
2026-05-01 Added serial number, fixed pinouts
    [ButtonComboModule.h, ktane.ino]
2026-05-01 Add compass calibration code for HMC5883L sensor
    Needs to just be run once before using. Resultant values need to be pasted into compass alignment module code (it is commented in where)
2026-05-01 Moved ultrasonic distance to after maze to prevent issue with encoders. Serial number on screen
    [CoreModule.h, FrequencyModule.h, ktane.ino]
2026-05-01 Update output message for calibration offsets
2026-05-01 Add signal alignment module integration
    nEED TO REWIRE SO THE MOZZI BUZZER IS ON d(, HAVE COMMENTED OUT THE startMozzi(CONTROL_RATE); for now so the rest of the code isnt affected
    [ktane.ino]
2026-05-01 Comment out audioHook for buzzer functionality
    Comment out audioHook function call to ensure buzzer works on D9.
    [ktane.ino]
2026-05-04 Serial number actualyl random and showing correctly. Fixed a few other things
    [ButtonComboModule.h, CoreModule.h, MazeModule.h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]
2026-05-05 Core overheating module now triggers randomly after module solve rather than time. Always triggers before completion
    [ktane.ino]
2026-05-05 Fixed pre game text
    [ktane.ino]
2026-05-05 Added bypass module mode, fixed distance and buttom combo module
    [ButtonComboModule.h, ktane.ino]
2026-05-06 activated all currently working modules
2026-05-07 Rapid beeps during core overheat. Fixed issue where core overheat may sometimes start right away
    [ButtonComboModule.h, CoreModule.h, MazeModule.h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]
2026-05-11 hopefully fixed btton auto pressing for final game
    [ButtonComboModule.h, ktane.ino]
2026-05-24 Replaced THS with microphone switch for core overheating game
    [CoreModule.h, ktane.ino]
2026-06-09 Removed serial number colisions for future use with wire cutting
2026-06-12 Added 3d files
    [Body.stl, DuPont Adaptor.stl, Lid.3mf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]
2026-06-12 Updated models
    [Lid.3mf, Lid.stl]
2026-06-13 Added manual and new designs
    [Body.stl, Lid.3mf, Lid.stl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]
2026-06-14 Fixed maze in game and site
    [MazeModule.h]
2026-06-14 Added SFX to BCM. Implemented and tested wire cutting logic
2026-06-15 Vibration motor
2026-06-20 Fixed core module deactivation. Fixed encoder directions
    [CoreModule.h, FrequencyModule.h, MazeModule.h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]
2026-06-20 Added lockout module back in. Fixed maze appearing early.
    [FrequencyModule.h, LockoutModule.h, MazeModule.h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]
2026-06-20 Fixed core randomisation, fixed encoder turn requirements
    [FrequencyModule.h, ktane.ino]
2026-06-21 Full manual and updated 3d files
    [Body.stl, DuPont Adaptor.stl, Lid.stl]
2026-06-21 Fixed not moving to loss state on time out
    [ktane.ino]
2026-06-21 Buzzer triggers microphone switch during core overheating module. Not working
    [CoreModule.h, ktane.ino]
2026-06-21 reverted core detection times
    [CoreModule.h]
2026-06-21 Started adding time gate to core module, not working, disabled
    [CoreModule.h, ktane.ino]
2026-06-22 Fixed LED bar lighting up after completing freq
    [FrequencyModule.h, ktane.ino]
2026-06-23 big red button uses serial number
    Needs the third digit of the serial number for the final button module
2026-06-24 Lockout now based on sn rather than always 1. Core module still not working
    [CoreModule.h, LockoutModule.h, ktane.ino]
2026-06-24 Core module blowing based on sampling, working properly. Fixed SN randomisaiton
    [CoreModule.h, ktane.ino]
2026-06-24 final .f3d model
    [Stop talking and Everybody Explodes.f3d]
2026-06-24 Changed wording for custom 3d printed enclosure
2026-06-24 Unified confirmation tones. Hopefully fixed occasional startup faliure
    [ButtonComboModule.h, FrequencyModule.h, LockoutModule.h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]
2026-06-24 Fixed timer hanging on 00:01 when running out of time
    [ktane.ino]
2026-06-24 Flipped LED bar pin reference, added LED bar startup animation
    [FrequencyModule.h, ktane.ino]
2026-06-24 Loosened core blowing params
    [CoreModule.h]
2026-06-24 Added vibrations back to core overheating. Tightened up freq detection time
    [FrequencyModule.h, ktane.ino]
2026-06-24 Big Red Button fail: Insta lose
    Changed the button to instant failure if you dont press it at the right time rather than a 3s penalty.
    [LockoutModule.h]
